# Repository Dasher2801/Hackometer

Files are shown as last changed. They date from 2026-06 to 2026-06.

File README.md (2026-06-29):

# Stardance CO2 & Environmental Monitor

A custom-designed, compact environmental monitoring board powered by the **ESP32-C3** microcontroller. This project features a high-precision **Sensirion SCD40** sensor to track CO2 levels, temperature, and relative humidity. Designed as part of the Hack Club Stardance hardware challenge.

---

## 🚀 Features

* **Brainpower:** Powered by the RISC-V ESP32-C3-WROOM-02 module supporting Wi-Fi and Bluetooth LE.
* **Precision Sensing:** Integrated Sensirion SCD40 for true photoacoustic $CO_2$ readings, ambient temperature, and humidity.
* **Thermal Isolation:** Features a dedicated physical PCB milling slot (isolation rout) to separate the sensor from the ESP32's operational heat, ensuring highly accurate temperature readings.
* **Display Output:** Dedicated I2C header pins to plug in a standard 0.96" SSD1306 OLED display.
* **Modern Interface:** USB-C connection for reliable power supply and easy flashing/debugging.
* **Hand-Solder Friendly:** Passive components use the 0805 SMD footprint, making it perfectly optimized for easy manual assembly.

---

## 🛠️ Hardware Architecture

### Key Components
* **MCU:** ESP32-C3-WROOM-02
* **Sensor:** Sensirion SCD40-D-R2 (LGA-20)
* **Power Regulator:** AP2112K-3.3V LDO (SOT-23-5)
* **Connector:** 16-pin USB-C (HRO TYPE-C-31-M-12)

### Pin Mapping
* **I2C SDA:** GPIO 8
* **I2C SCL:** GPIO 9
* **USB D-:** GPIO 18
* **USB D+:** GPIO 19

---

## 📁 Repository Structure

* `/hardware` - Contains the KiCad project files, schematics, and PCB layouts.
* `/gerbers` - Production-ready Gerber and Drill files (`.zip` format) for manufacturing.
* `BOM.md` - Complete Bill of Materials with exact hardware designators and component values.

---

## 🔧 Production & Assembly Notes

1. **PCB Fabrication:** The Gerber files are optimized for standard 2-layer manufacturing (1.6mm thickness recommended). Ensure your manufacturer supports internal cutouts/slots for the thermal isolation barrier.
2. **RF Performance:** The top edge of the PCB keeps a strict copper-free clearance zone around the ESP32 onboard antenna to guarantee optimal Wi-Fi and Bluetooth signal strength.
3. **Soldering the SCD40:** Because the SCD40 is an LGA package with pads located entirely underneath the chip, utilizing solder paste and a hot-air rework station (or a reflow heat plate) is highly recommended for assembly.
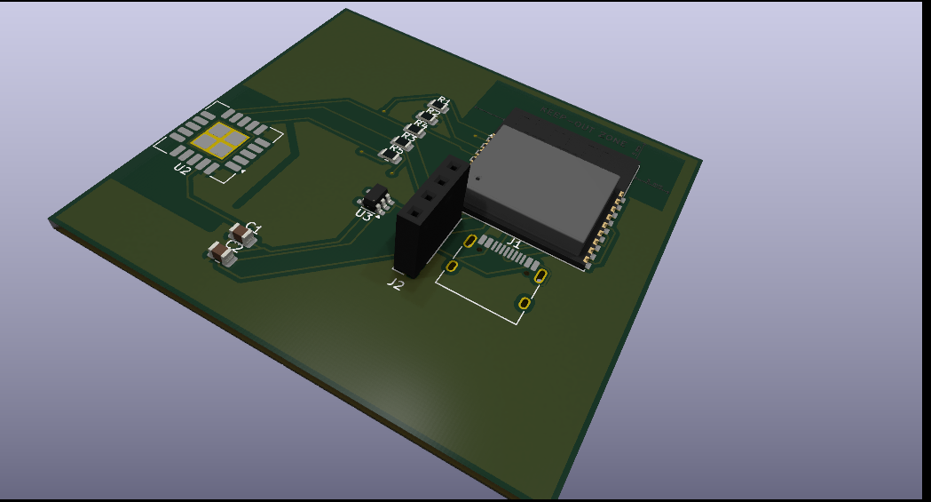
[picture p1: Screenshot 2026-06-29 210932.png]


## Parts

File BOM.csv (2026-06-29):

## 1. Hauptkomponenten & ICs
| Bauteil-ID | Bezeichnung | Beschreibung | Gehäuseform (Package) | Menge |
| :--- | :--- | :--- | :--- | :--- |
| U1 | ESP32-C3-WROOM-02 | Haupt-Mikrocontroller mit Wi-Fi und Bluetooth | SMD Module | 1 |
| U2 | Sensirion SCD40-D-R2 | Hochpräziser CO2-, Temperatur- und Luftfeuchtigkeitssensor | LGA-20 (10.1x10.1mm) | 1 |
| U3 | AP2112K-3.3 | LDO-Spannungsregler (5V zu stabilen 3.3V) | SOT-23-5 | 1 |
## 2. Anschlüsse & Steckverbinder
| Bauteil-ID | Bezeichnung | Beschreibung | Gehäuseform / Typ | Menge |
| :--- | :--- | :--- | :--- | :--- |
| J1 | USB-C Receptacle (16-Pin) | USB-C Buchse für Strom und Programmierung | HRO TYPE-C-31-M-12 | 1 |
| J2 | Display-Header (4-Pin) | Buchsenleiste zum Aufstecken des OLED-Displays | Lochraster 1x04, 2.54mm Pitch | 1 |
| — | OLED-Display | Passendes I2C-Display (z.B. 0.96" SSD1306) | 4-Pin (VCC, GND, SCL, SDA) | 1 |
## 3. Widerstände (SMD, Baugröße 0805)
| Bauteil-ID | Wert | Funktion | Menge |
| :--- | :--- | :--- | :--- |
| R1 | 5.1 kΩ | USB-C CC1 Pull-Down (erzwingt 5V-Stromausgabe) | 1 |
| R2 | 5.1 kΩ | USB-C CC2 Pull-Down (erzwingt 5V-Stromausgabe) | 1 |
| R3 | 4.7 kΩ | I2C-Bus SCL Pull-Up-Widerstand | 1 |
| R4 | 4.7 kΩ | I2C-Bus SDA Pull-Up-Widerstand | 1 |
| R5 | 10 kΩ | ESP32 EN Pull-Up für stabilen Bootvorgang | 1 |
## 4. Kondensatoren (SMD, Baugröße 0805)
| Bauteil-ID | Wert | Funktion | Menge |
| :--- | :--- | :--- | :--- |
| C1 | 100 nF | Stützkondensator am 3.3V-Ausgang des Reglers | 1 |
| C2 | 100 nF | Filterkondensator zwischen USB-Shield und System-GND | 1 |

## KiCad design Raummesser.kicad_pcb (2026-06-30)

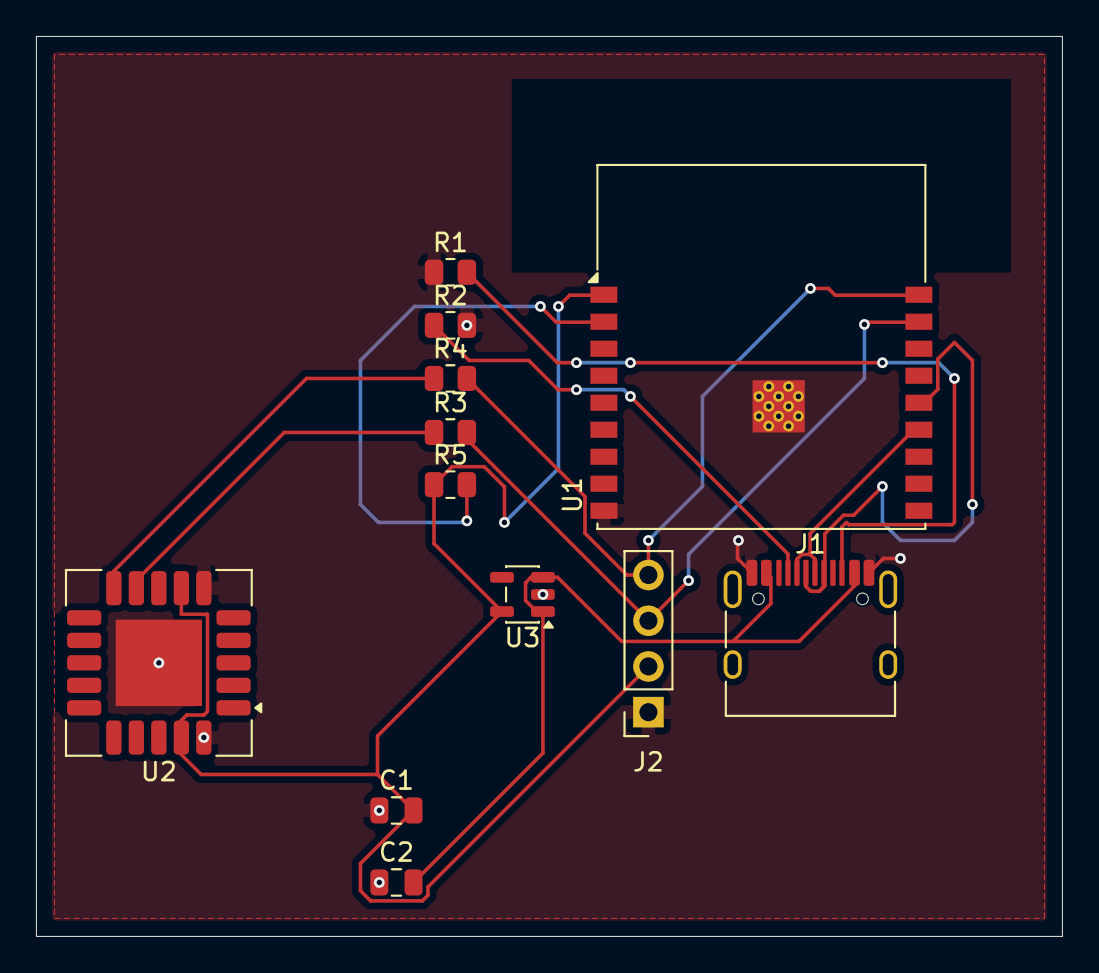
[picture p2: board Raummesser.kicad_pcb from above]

Board: 2 copper layers, 57.0 x 50.0 mm, 12 parts (0 on the bottom side), 11 nets.

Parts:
C1, C2: 10µF; C_0805_2012Metric
J1: USB_C_Receptacle_USB2.0_16P; USB_C_Receptacle_HRO_TYPE-C-31-M-12
J2: Display; PinSocket_1x04_P2.54mm_Vertical
R1: 5.1k; R_0805_2012Metric
R2: 5,1k; R_0805_2012Metric
R3, R4: 4,7k; R_0805_2012Metric
R5: 10k; R_0805_2012Metric
U1: ESP32-C3-WROOM-02
U2: SCD40-D-R2; Sensirion_SCD4x-1EP_10.1x10.1mm_P1.25mm_EP4.8x4.8mm
U3: AP2112K-3.3; SOT-23-5

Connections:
GND: C1.1, C2.1, J1.A1 (GND), J1.A12 (GND), J1.B1 (GND), J1.B12 (GND), J2.1, R1.1, R2.2, U1.9 (GND), U1.19 (GND), U2.6 (GND), U2.20 (GND), U2.21 (GND), U3.2 (GND)
unnamed: J1.A5 (CC1), J1.A6 (D+), J1.B6 (D+), R2.1, U1.14 (IO19)
unnamed: J1.B5 (CC2), R1.2
unnamed: C1.2, J2.2, R5.1, U1.1 (3V3), U2.7 (VDD), U2.19 (VDD), U3.5 (VOUT)
unnamed: J2.3, R3.2, U1.17 (IO1)
unnamed: J2.4, R4.2, U1.18 (IO0)
unnamed: R5.2, U1.2 (EN)
unnamed: J1.A7 (D-), J1.B7 (D-), U1.13 (IO18)
unnamed: R3.1, U2.9 (SCL)
unnamed: R4.1, U2.10 (SDA)
unnamed: C2.2, J1.A4 (VBUS), J1.A9 (VBUS), J1.B4 (VBUS), J1.B9 (VBUS), U3.1 (VIN), U3.3 (EN)

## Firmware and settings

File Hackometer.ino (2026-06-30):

#include <Arduino.h>
#include <Wire.h>
#include <SensirionI2cScd4x.h>
#include <Adafruit_GFX.h>
#include <Adafruit_SSD1306.h>

#define SCREEN_WIDTH 128
#define SCREEN_HEIGHT 64
#define OLED_RESET    -1
#define SCREEN_ADDRESS 0x3C

Adafruit_SSD1306 display(SCREEN_WIDTH, SCREEN_HEIGHT, &Wire, OLED_RESET);
SensirionI2cScd4x scd4x;

const int I2C_SDA = 8; 
const int I2C_SCL = 9;

void setup() {
  Serial.begin(115200);
  
  Wire.begin(I2C_SDA, I2C_SCL);

  if(!display.begin(SSD1306_SWITCHCAPVCC, SCREEN_ADDRESS)) {
    Serial.println(F("OLED Display wurde nicht gefunden!"));
    for(;;);
  }
  
  display.clearDisplay();
  display.setTextSize(1);
  display.setTextColor(SSD1306_WHITE);
  display.setCursor(10, 20);
  display.println("Raummesser v1.0");
  display.setCursor(10, 35);
  display.println("Starte Sensor...");
  display.display();

  scd4x.begin(Wire);

  uint16_t error;
  char errorMessage[256];
  error = scd4x.stopPeriodicMeasurement();
  if (error) {
    Serial.print("Fehler beim Stoppen der Messung: ");
    errorToString(error, errorMessage, 256);
    Serial.println(errorMessage);
  }

  error = scd4x.startPeriodicMeasurement();
  if (error) {
    Serial.print("Fehler beim Starten der Messung: ");
    errorToString(error, errorMessage, 256);
    Serial.println(errorMessage);
  }

  Serial.println("System erfolgreich gestartet!");
  delay(1000);
}

void loop() {
  uint16_t co2 = 0;
  float temperature = 0.0f;
  float humidity = 0.0f;
  bool isDataReady = false;
  uint16_t error;
  char errorMessage[256];

  error = scd4x.getDataReadyFlag(isDataReady);
  if (error) {
    Serial.print("Fehler beim Lesen des Daten-Status: ");
    errorToString(error, errorMessage, 256);
    Serial.println(errorMessage);
    return;
  }

  if (isDataReady) {
    error = scd4x.readMeasurement(co2, temperature, humidity);
    
    if (!error) {
      Serial.print("CO2: "); Serial.print(co2); Serial.println(" ppm");
      Serial.print("Temperatur: "); Serial.print(temperature); Serial.println(" *C");
      Serial.print("Luftfeuchtigkeit: "); Serial.print(humidity); Serial.println(" %");
      Serial.println("-------------------------------------");

      display.clearDisplay();
      
      display.setTextSize(1);
      display.setCursor(20, 0);
      display.println("- CO2 MONITOR -");
      
      display.setCursor(15, 18);
      display.setTextSize(2);
      display.print(co2);
      display.setTextSize(1);
      display.print(" ppm");
      
      display.writeLine(0, 40, 128, 40, SSD1306_WHITE);
      
      display.setTextSize(1);
      display.setCursor(0, 46);
      display.print("Temp:   "); 
      display.print(temperature, 1);
      display.print(" C");
      
      display.setCursor(0, 56);
      display.print("Feucht: "); 
      display.print(humidity, 1);
      display.print(" %");
      
      display.display();
    }
  }

  delay(1000);
}
